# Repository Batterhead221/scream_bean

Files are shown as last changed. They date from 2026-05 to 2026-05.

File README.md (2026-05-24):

# SCREAM_BEAN_REV_B

<p align="center">
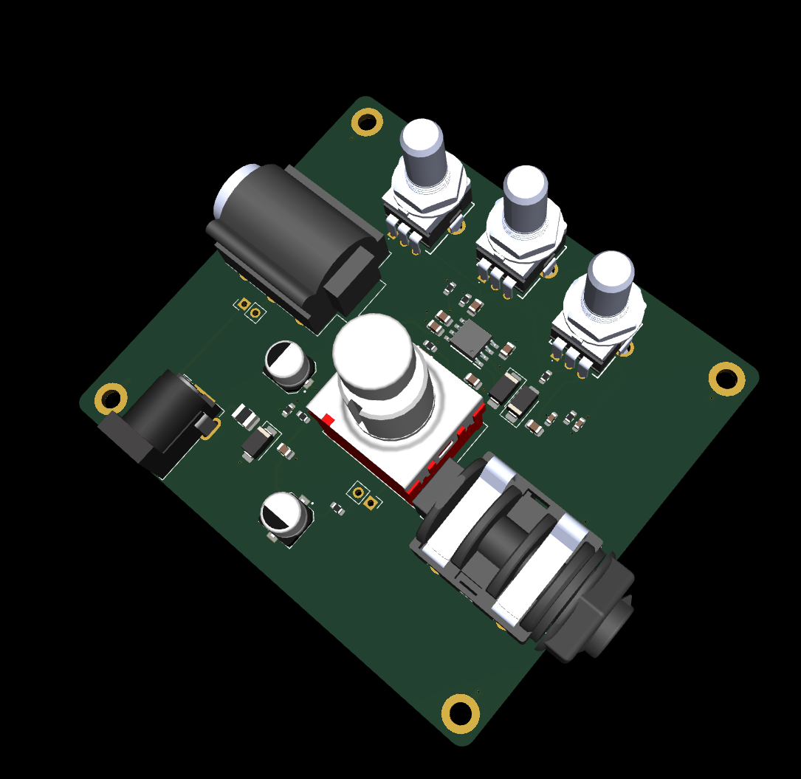
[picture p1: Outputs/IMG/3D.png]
SCREAM_BEAN_REV_B top 3D board render
  
</p>

Project Status

This revision is intended to improve the original SCREAM_BEAN layout and move the board closer to a clean, buildable pedal PCB.

System Role

Guitar input
    ↓
input buffer / gain and clipping stages
    ↓
tone / level shaping
    ↓
output to amplifier or next pedal

Key Specs

Board role - Analog guitar drive/distortion pedal PCB
Revision - Rev B
Circuit style - Tube Screamer-inspired overdrive/distortion
Sound target - Early-2000s pop-punk drive
Power direction - 9V pedal supply / battery-style pedal ecosystem
Controls - Drive / tone / level style pedal controls
Audio path - Analog
Board type - Stompbox effects pedal PCB

Main Features

Analog guitar input/output signal path
Drive/clipping stage
Tone-shaping network
Output level control
Pedal-style power input direction
Compact board layout for enclosure use
Silkscreen labels for bring-up and assembly
Revision B layout improvements

SCREAM_BEAN_REV_B is inspired by the Tube Screamer topology, but it is not meant to be a component-perfect clone.

Design priorities:

Build a working analog drive circuit
Learn op-amp gain/clipping behavior
Shape the tone for pop-punk rhythm guitar
Keep the board understandable and buildable
Use layout practices that make audio debugging easier

Power Notes

Pedal power should be treated carefully.

pedal supply / battery input
        ↓
protection / filtering
        ↓
audio circuit power rail

Common first checks:
no sound      → check power, input/output jack wiring, IC orientation
weak sound    → check gain stage values and pot wiring
harsh/fizzy   → check clipping diode orientation and tone network
hum/noise     → check grounding and cable/enclosure wiring
oscillation   → check layout, power decoupling, and high-gain routing

Design Notes
Keep audio input routing away from noisy power routing.
Keep gain-stage feedback paths short.
Keep power decoupling close to the IC.
Use clear labels for pots, jacks, power, and switch wiring.
Confirm enclosure fit before ordering a panelized or final version.
Expect component value experiments while tuning the sound.

Repository Output Images

Expected image paths for GitHub README rendering:

Outputs/
  IMG/
    3D-T.png
    3D-B.png
    SCHEMATIC.png
    L1-SIG.png
    L2-GND.png

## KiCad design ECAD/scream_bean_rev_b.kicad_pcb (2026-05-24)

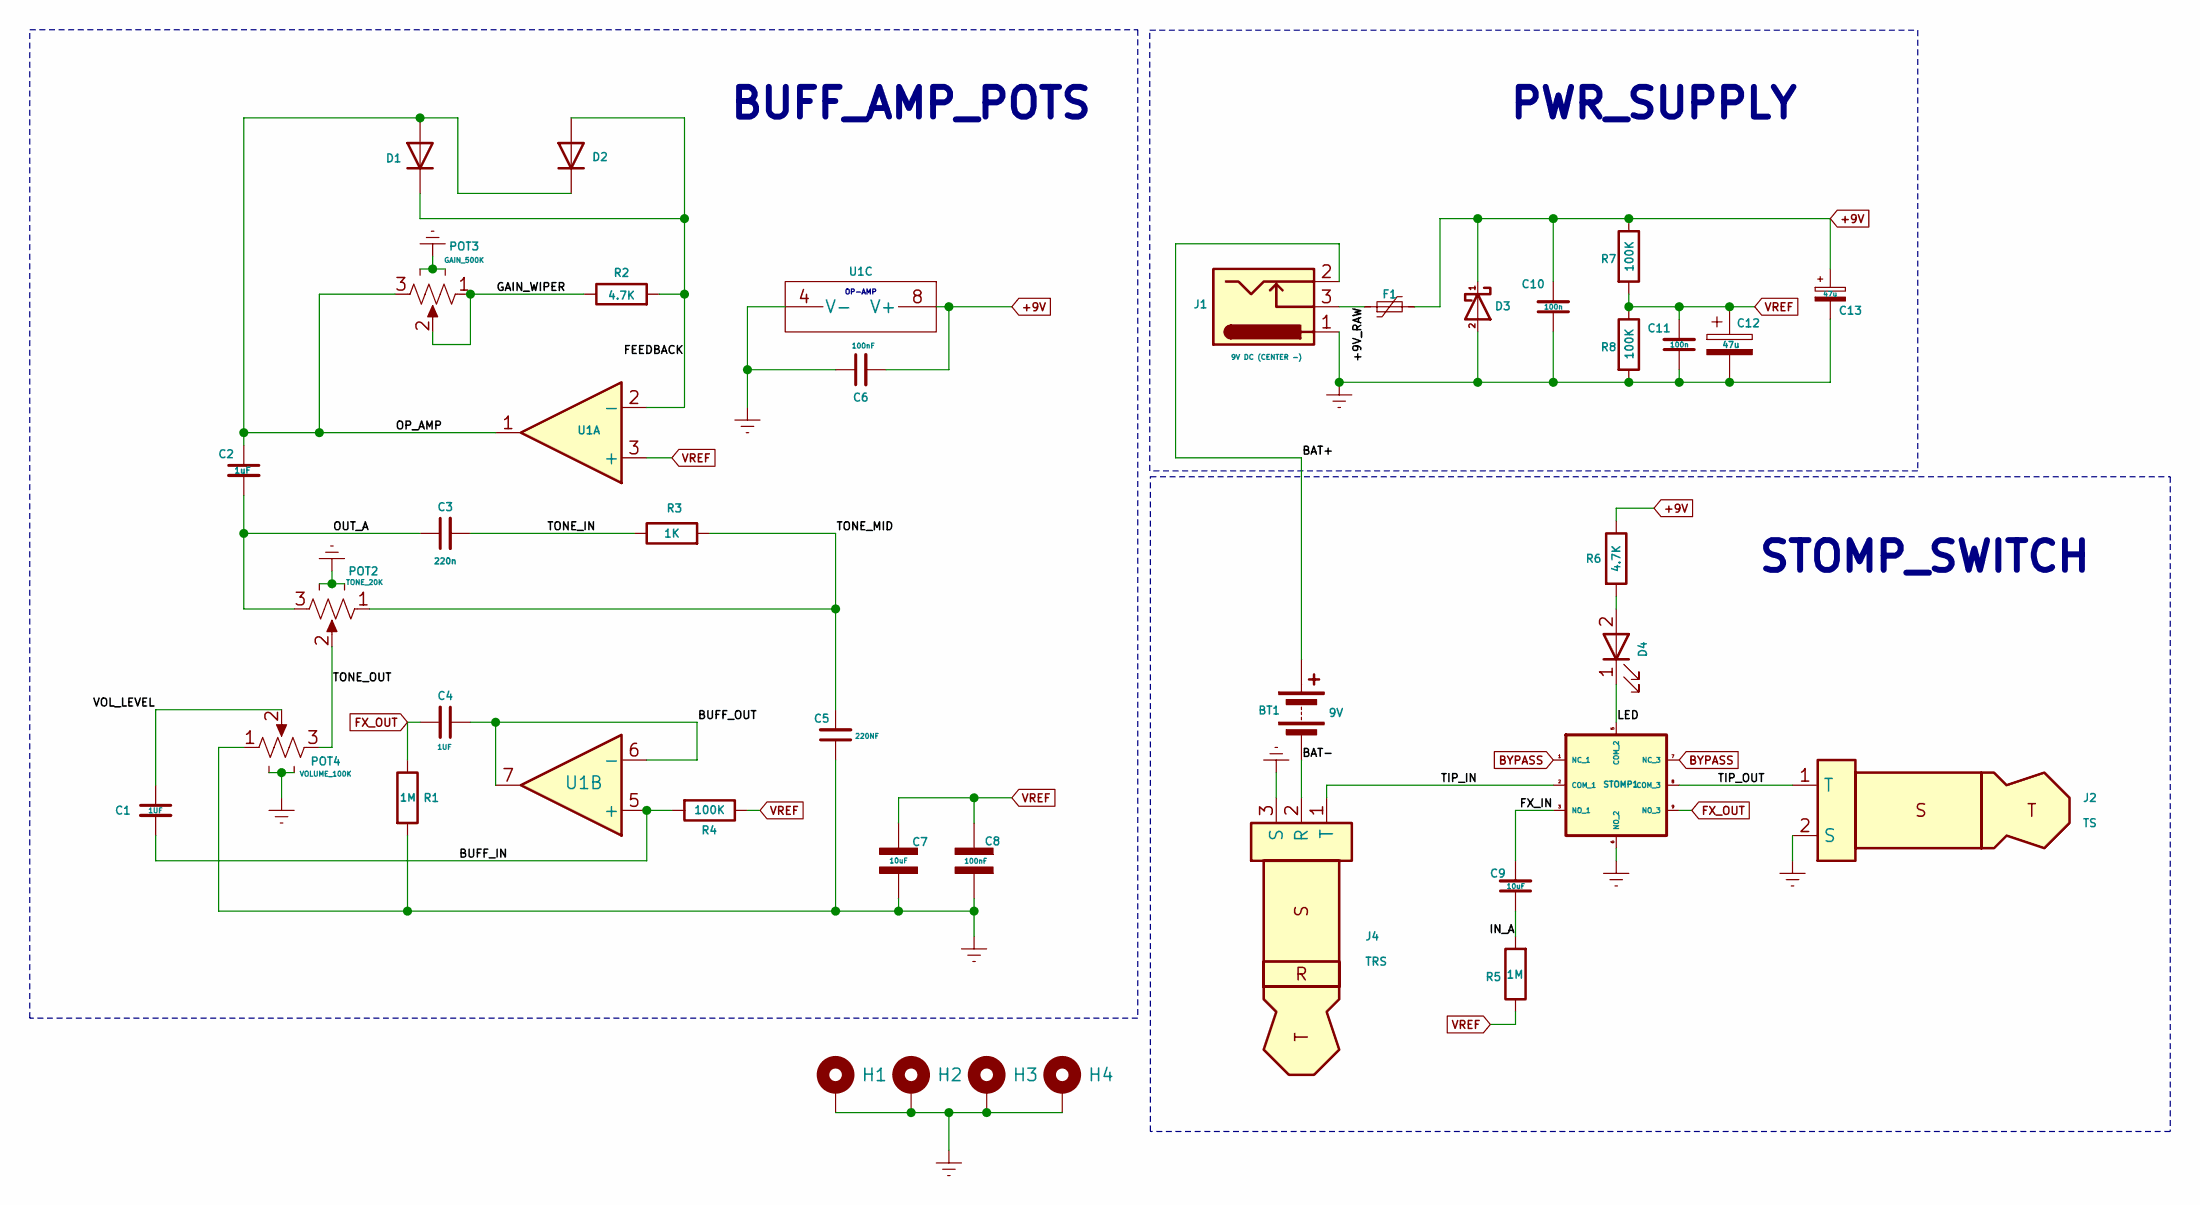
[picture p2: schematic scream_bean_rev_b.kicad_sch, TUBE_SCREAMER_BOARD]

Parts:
BT1: 9V; PinHeader_1x02_P2.54mm_Vertical
C1, C4: 1UF; C_0805_2012Metric; Voltage 25V; Tolerance 20%
C2: 1uF; C_0805_2012Metric; Voltage 6.3V; Tolerance 20%
C3: 220n; C_0603_1608Metric; Voltage 25V; Tolerance 20%
C5: 220NF; C_0603_1608Metric; Voltage 6.3V; Tolerance 20%
C6: 100nF; C_0805_2012Metric; Voltage 25V; Tolerance 20%
C7: 10uF; C_1206_3216Metric; DigiKey_Part_Number 490-18214-1-ND
C8: 100nF; C_0805_2012Metric; DigiKey_Part_Number 490-3261-1-ND
C9: 10uF; C_1206_3216Metric; Voltage 25V; Tolerance 20%
C10, C11: 100n; C_0805_2012Metric; Voltage 6.3V; Tolerance 20%
C12: 47u; CAP_EEEFK1E470P
C13: 47u; CAP_EEEFK1E470P; Voltage 6.3V; Tolerance 20%
D1, D2: 1N4148; D_SMA
D3: 1N5817; D_SMA
D4: LED; PinHeader_1x02_P2.54mm_Vertical
F1: Polyfuse_Small; Fuse_1210_3225Metric
H1, H2, H3, H4: MountingHole; MountingHole_3.2mm_M3_ISO14580_Pad_TopBottom
J1: 9V DC (CENTER -); BarrelJack_GCT_DCJ200-10-A_Horizontal
J2: TS; Jack_6.35mm_Neutrik_NMJ4HCD2_Horizontal
J4: TRS; Jack_6.35mm_Neutrik_NMJ6HCD2_Horizontal
POT2: TONE_20K; RD901F4015R1B100K00DL1
POT3: GAIN_500K; RD901F4015R1B100K00DL1
POT4: VOLUME_100K; RD901F4015R1B100K00DL1
R1, R5: 1M; R_0603_1608Metric
R2, R6: 4.7K; R_0603_1608Metric
R3: 1K; R_0603_1608Metric
R4, R7, R8: 100K; R_0603_1608Metric
STOMP1: FS57003PLT2B2M2QE; SW_FS57003PLT2B2M2QE
U1: NJM4558; SOIC127P680X200-8N

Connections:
+9V: C6.2, C10.2, C13.1, D3.1 (K), F1.2, R6.1, R7.1, U1.8 (V+)
/+9V_RAW: F1.1, J1.3 (GNDBREAK)
/BAT+: BT1.1 (+), J1.2 (GND)
/BAT-: BT1.2 (-), J4.2 (R)
/BUFF_IN: C1.2, R4.2, U1.5 (+)
/BUFF_OUT: C4.1, U1.6 (-), U1.7
/FEEDBACK: D1.1 (K), D2.2 (A), R2.2, U1.2 (-)
/FX_IN: C9.2, STOMP1.3 (NO_1)
/GAIN_WIPER: POT3.1, POT3.2, R2.1
/IN_A: C9.1, R5.2
/LED: D4.1 (K), STOMP1.5 (COM_2)
/OP_AMP: C2.1, D1.2 (A), D2.1 (K), POT3.3, U1.1
/OUT_A: C2.2, C3.1, POT2.3
/TIP_IN: J4.1 (T), STOMP1.2 (COM_1)
/TIP_OUT: J2.1 (T), STOMP1.8 (COM_3)
/TONE_IN: C3.2, R3.1
/TONE_MID: C5.2, POT2.1, R3.2
/TONE_OUT: POT2.2, POT4.3
/VOL_LEVEL: C1.1, POT4.2
BYPASS: STOMP1.1 (NC_1), STOMP1.7 (NC_3)
EARTH: C5.1, C6.1, C7.1, C8.1, C10.1, C11.1, C12.2, C13.2, D3.2 (A), H1.1 (1_1), H2.1 (1_1), H3.1 (1_1), H4.1 (1_1), J1.1 (PWR), J2.2 (S), J4.3 (S), POT2.4 (CASE), POT2.5 (CASE), POT3.4 (CASE), POT3.5 (CASE), POT4.1, POT4.4 (CASE), POT4.5 (CASE), R1.2, R8.2, STOMP1.6 (NO_2), U1.4 (V-)
FX_OUT: C4.2, R1.1, STOMP1.9 (NO_3)
unnamed: D4.2 (A), R6.2
VREF: C7.2, C8.2, C11.2, C12.1, R4.1, R5.1, R7.2, R8.1, U1.3 (+)

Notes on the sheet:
OP-AMP
STOMP_SWITCH
PWR_SUPPLY
BUFF_AMP_POTS

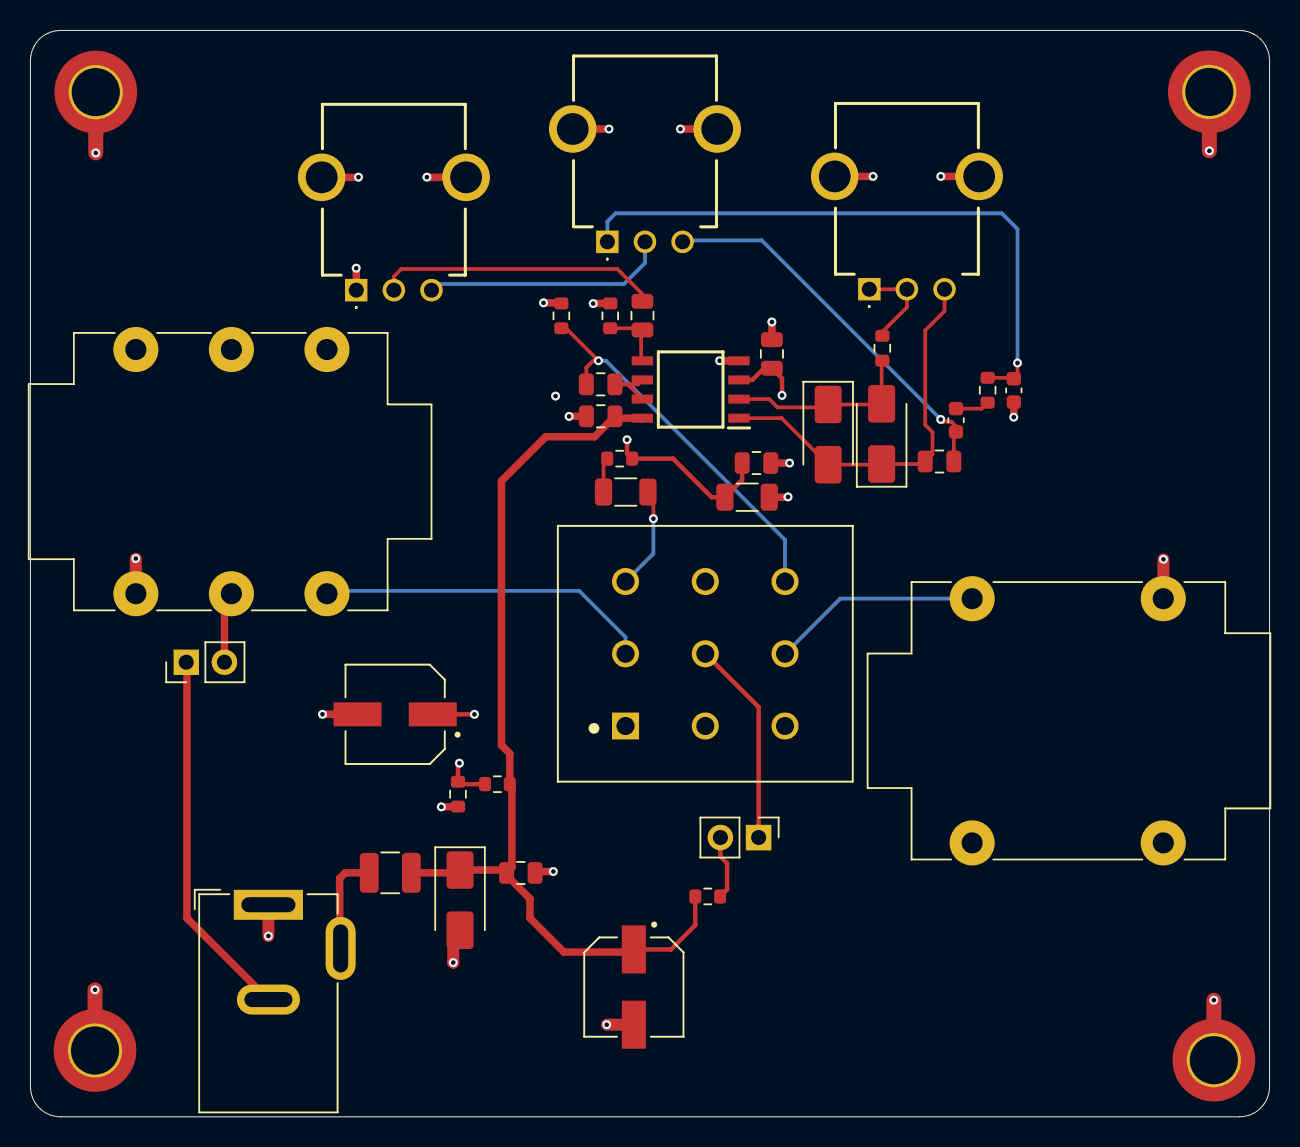
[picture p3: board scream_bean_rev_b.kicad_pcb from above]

Board: 4 copper layers, 82.3 x 72.2 mm, 39 parts (0 on the bottom side), 24 nets.
